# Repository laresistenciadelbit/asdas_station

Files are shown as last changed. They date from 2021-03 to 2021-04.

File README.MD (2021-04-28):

# (A)rduino (S)im (D)ata (A)cquisition (S)ystem

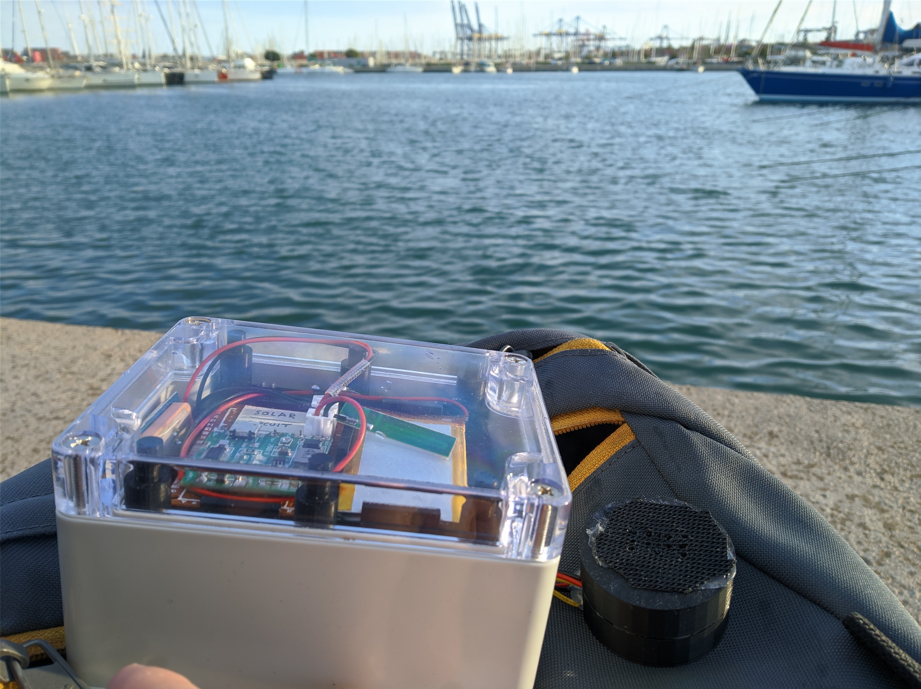
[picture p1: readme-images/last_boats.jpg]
alt asdas_station


[FULL DOCUMENTATION (SPANISH)](https://github.com/laresistenciadelbit/varios/raw/master/ASDAS_PUBLIC_LITE.PDF)

## SPANISH

Arduino Sim Data Acquisition System es un proyecto que cubre toda la parte de
adquisición de datos de sensores desde el circuito físico, a la transmisión de los datos,su almacenaje, y su visualización en tiempo real desde un navegador Web.

Un dispositivo estación hecho con Arduino envía peticiones JSON HTTP POST al servidor.

Este repositorio de Github almacena la parte del dispositivo estación.

La parte del servidor la puedes encontrar en:
[https://github.com/laresistenciadelbit/asdas](https://github.com/laresistenciadelbit/asdas)

#### ESTACIÓN ASDAS

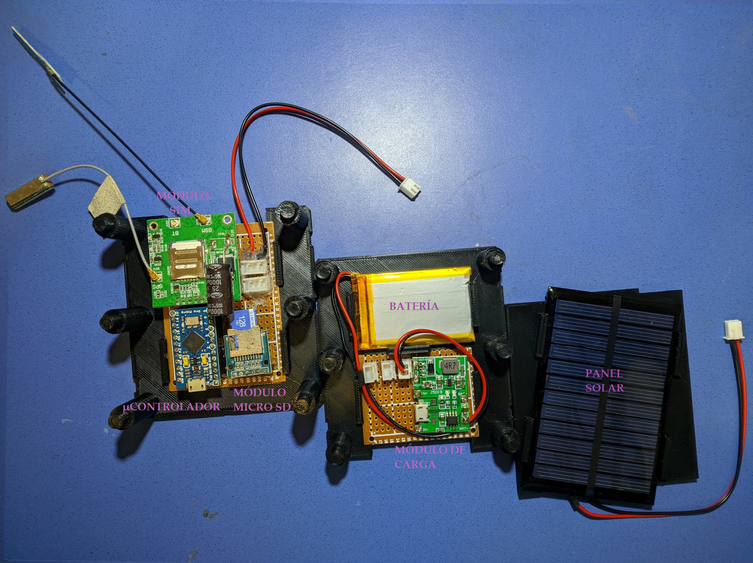
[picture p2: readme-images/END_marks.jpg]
alt asdas_station_circuit


La estación cuenta con un módulo SIM para mandar los datos por la red móvil, un microcontrolador (Arduino Pro Micro versión 3.3V), un lector de tarjetas Micro SD para almacenar los datos que no se hubiesen podido enviar por falta de señal, y un sistema de autonomía con batería, panel solar y un conversor de voltaje que distribuye la energía y carga la batería. También se le añadirán tantos sensores como se desee (hasta el límite de entradas del microcontrolador)

#### CARPETAS DEL PROYECTO

- arduino_sketch

>Aquí encontrarás el sketch para compilarlo en arduino. 

>He tomado la librería oficial de sim808 y la he modificado para hacerla compatible con más módulos y he añadido alguna función.
Es necesario usarla para que funcione el sketch:

[https://github.com/laresistenciadelbit/sim8xx](https://github.com/laresistenciadelbit/sim8xx)

>###### Se instala como el resto de librerías: Se pega su contenido en la carpeta libraries de la carpeta Arduino (o bien la que aparece en mis documentos o bien en la de instalación del programa)

.
- kicad_project

>Aquí encontrarás los esquemas del prototipo de pcb y circuito en formato kicad

.

- blender

>Aquí encontrarás los modelos 3d que forman la estructura para el prototipo

.

alt asdas_station_circuit_timelapse

___
.
## ENGLISH

ASDAS is a project which covers all the data acquisition part of sensors starting from the physical circuit followed by the data transmission, its storage and visualization in real time from a Web Browser.

A station device made with Arduino send HTTP POST JSON messages to the server.

This Github project is the station part.

The server Github can be accessed from:

[https://github.com/laresistenciadelbit/asdas](https://github.com/laresistenciadelbit/asdas)

#### ASDAS STATION

alt asdas_station_circuit

The station counts with a Sim module for sending data to the server throught the mobile network, a microcontroller (Arduino Pro Micro 3.3V), a micro SD reader for storing the data that wouldn't be delivered to the server by signal fail, and an autonomous energy system with battery, solar panel and voltage conversor which distributes energy and charges the battery. Also ther will be added so many sensors as is wished (until the microcontroller I/O ports limit)

#### PROJECT FOLDERS

- arduino_sketch

>Here you can get the sketch for compiling in Arduino

> I've took the official sim808 library and I've modified it for making compatible with more Sim modules and I've also added some function.
The library must be used with this sketch to work:
[https://github.com/laresistenciadelbit/sim8xx](https://github.com/laresistenciadelbit/sim8xx)

>###### The install process for the library is the same like other libraries: Just paste its content in the "libraries" folder from the install directory or "my documents/Arduino" directory.

.
- kicad_project

>Here you can get the pcb and circuit schemas in KiCad format.

.

- blender

>Here you can get the 3d models of the created structure for the prototype

.

alt asdas_station_circuit_timelapse

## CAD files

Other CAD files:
blender_3d_model/tfg_box_battery_v0.d.blend
blender_3d_model/tfg_box_battery_v0.d_HOLED.blend
blender_3d_model/tfg_box_level_v0.8.blend
blender_3d_model/tfg_box_level_v0.8_HOLED.blend
blender_3d_model/tfg_box_solar_v0.B.blend
blender_3d_model/tfg_box_solar_v0.B_HOLED.blend

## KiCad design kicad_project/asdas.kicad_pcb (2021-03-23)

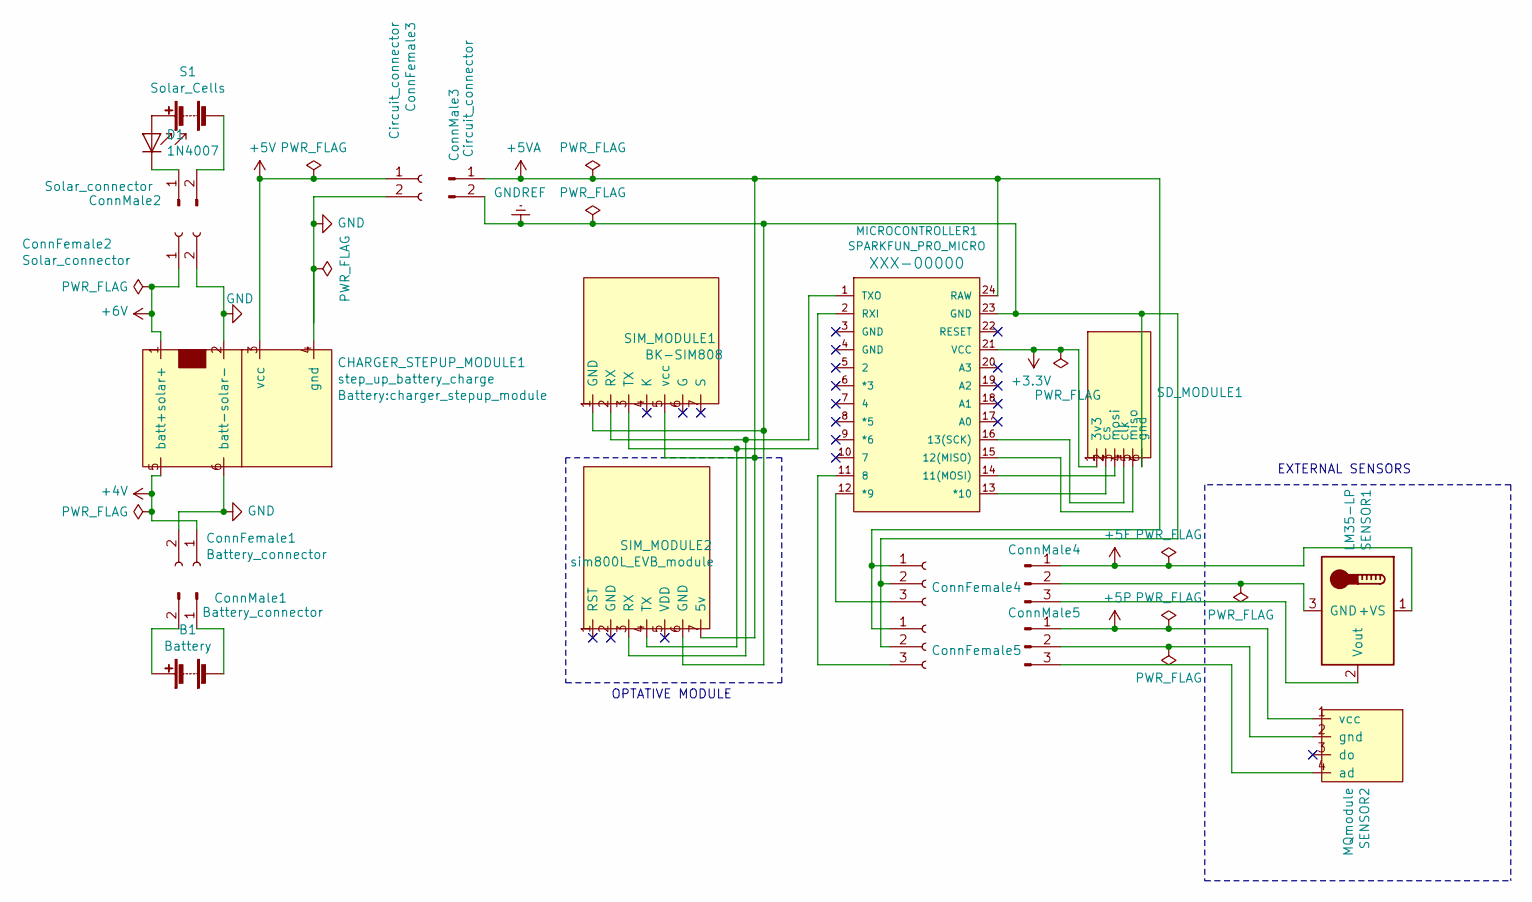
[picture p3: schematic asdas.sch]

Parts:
B1: Battery; battery_523450
CHARGER_STEPUP_MODULE1: step_up_battery_charge; charger_stepup_module
ConnFemale1: Battery_connector; JST_EH_B2B-EH-A_1x02_P2.50mm_Vertical
ConnFemale2: Solar_connector; JST_EH_B2B-EH-A_1x02_P2.50mm_Vertical
ConnFemale3: Circuit_connector; JST_EH_B2B-EH-A_1x02_P2.50mm_Vertical
ConnFemale4: Sensor1_connector; JST_EH_B3B-EH-A_1x03_P2.50mm_Vertical
ConnFemale5: Sensor2_connector; JST_EH_B3B-EH-A_1x03_P2.50mm_Vertical
ConnMale1: Battery_connector; JST_EH_B2B-EH-A_1x02_P2.50mm_Vertical
ConnMale2: Solar_connector; JST_EH_B2B-EH-A_1x02_P2.50mm_Vertical
ConnMale3: Circuit_connector; JST_EH_B2B-EH-A_1x02_P2.50mm_Vertical
ConnMale4: Sensor1_connector; JST_EH_B3B-EH-A_1x03_P2.50mm_Vertical
ConnMale5: Sensor2_connector; JST_EH_B3B-EH-A_1x03_P2.50mm_Vertical
D1: 1N4007; D_DO-41_SOD81_P10.16mm_Horizontal
MICROCONTROLLER1: SPARKFUN_PRO_MICRO
S1: Solar_Cells; solar_cell
SD_MODULE1: sd_reader_2
SENSOR1: LM35-LP; lm35
SENSOR2: MQmodule
SIM_MODULE1: BK-SIM808
SIM_MODULE2: sim800L_EVB_module; sim800L_EVB_module(fixedsize)

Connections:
+3V3: MICROCONTROLLER1.21 (VCC), SD_MODULE1.1 (3v3)
+4V: CHARGER_STEPUP_MODULE1.5 (batt+), ConnFemale1.1
+5F: ConnMale4.1, SENSOR1.1 (+VS)
+5P: ConnMale5.1, SENSOR2.1 (vcc)
+5V: CHARGER_STEPUP_MODULE1.3 (vcc), ConnFemale3.1
+5VA: ConnFemale4.1, ConnFemale5.1, ConnMale3.1, MICROCONTROLLER1.24 (RAW), SIM_MODULE1.5 (vcc), SIM_MODULE2.7 (5v)
+6V: CHARGER_STEPUP_MODULE1.1 (solar+), ConnFemale2.1
GND: CHARGER_STEPUP_MODULE1.2 (solar-), CHARGER_STEPUP_MODULE1.4 (gnd), CHARGER_STEPUP_MODULE1.6 (batt-), ConnFemale1.2, ConnFemale2.2, ConnFemale3.2
GNDREF: ConnFemale4.2, ConnFemale5.2, ConnMale3.2, MICROCONTROLLER1.23 (GND), SD_MODULE1.6 (gnd), SIM_MODULE1.1 (GND), SIM_MODULE2.6 (GND)
unnamed: B1.1 (+), ConnMale1.2
unnamed: B1.2 (-), ConnMale1.1
unnamed: ConnFemale4.3, MICROCONTROLLER1.12 (*9)
unnamed: ConnFemale5.3, MICROCONTROLLER1.11 (8)
unnamed: ConnMale2.1, D1.1 (K)
unnamed: ConnMale2.2, S1.2 (-)
unnamed: ConnMale4.2, SENSOR1.3 (GND)
unnamed: ConnMale4.3, SENSOR1.2 (Vout)
unnamed: ConnMale5.2, SENSOR2.2 (gnd)
unnamed: ConnMale5.3, SENSOR2.4 (ad)
unnamed: D1.2 (A), S1.1 (+)
unnamed: MICROCONTROLLER1.1 (TXO), SIM_MODULE1.2 (RX), SIM_MODULE2.3 (RX)
unnamed: MICROCONTROLLER1.2 (RXI), SIM_MODULE1.3 (TX), SIM_MODULE2.4 (TX)
unnamed: MICROCONTROLLER1.13 (*10), SD_MODULE1.2 (cs)
unnamed: MICROCONTROLLER1.14 (11(MOSI)), SD_MODULE1.3 (mosi)
unnamed: MICROCONTROLLER1.15 (12(MISO)), SD_MODULE1.5 (miso)
unnamed: MICROCONTROLLER1.16 (13(SCK)), SD_MODULE1.4 (clk)

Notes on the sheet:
EXTERNAL SENSORS
OPTATIVE MODULE

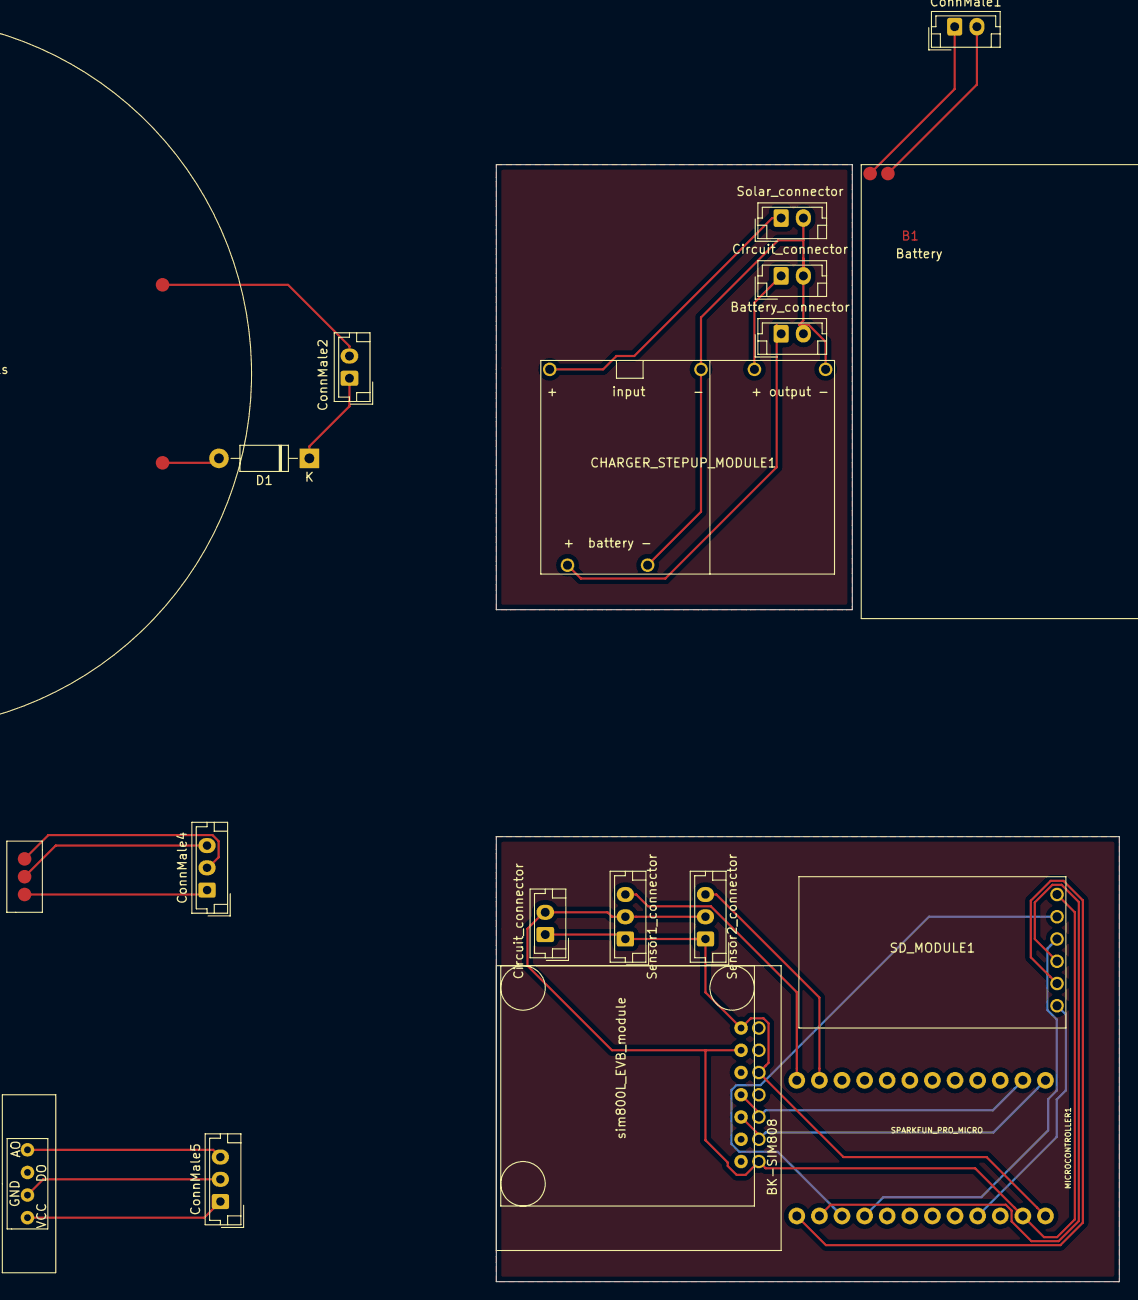
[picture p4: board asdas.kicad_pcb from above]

Board: 2 copper layers, 20 parts (0 on the bottom side), 26 nets.

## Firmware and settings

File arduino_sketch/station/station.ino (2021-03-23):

/*	-Proyecto:	Arduino Sim Data Acquisition System 
	-Autor:		Noel Fernández Peral
	-Requisitos:
		<>Hardware:
			[]Arduino pro micro (Compatible con otras variantes)
			[]Módulo Sim8xx (Cualquier variante de sim800 es compatible)
			[]Módulo de lectura/escritura de tarjeta micro SD
*/
	//definimos el identificador del módulo
#define ID "estación 1"
	//definimos una contraseña para las peticiones
#define PASSWD "1AeIoU!9"
	//Definimos si usaremos gps o no (módulos sim808 y sim868)
#define USE_GPS  1
	//Definimos cuantas estadísticas queremos enviar (sin contar la localización gps)
#define SEND_STATUS 1
	//Definimos si estamos en modo depuración o no
//#define DEBUGGING false // <-- dentro de la clase ModuleManager, ya que el pasarsela como constante asignando a una variable hacía que precompilase el código de debug aunque no se usase
	//Definimos el código pin si la tarjeta lo tiene activo
//#define UNLOCK_PIN "0000"
	//Definimos los credenciales del APN para el uso de GPRS
#define GPRS_APN "internet"
#define GPRS_USER   ""
#define GPRS_PASS   ""
	//pines que usaremos (pines RX y TX dedicados)( RST Y PWKEY para algunos modelos de sim808 y sim7600e )
//#define PIN_RX 		0   USAMOS Serial1 que es puerto de serie por hardware, siempre són los pines 0 y 1 (RXI y TX0) en arduino pro micro
//#define PIN_TX 		1

#define  PIN_RST   7
#define  PIN_PWKEY 6

  //Definimos los pines de los sensores que queremos leer (podemos poner tantos como queramos. *el límite son los pines y la memoria)
#define  SENSOR_NUMBER 2
const uint8_t  sensor_pin[SENSOR_NUMBER]={8,9};
const char  sensor_name[][30]={"temperatura","CO"};
	//Definimos si queremos que se active un pin de salida ante una entrada concreta en el sensor 1
//#define PIN_OUTPUT 13
	//Definimos el valor del sensor 1 para el cual activará el PIN_OUTPUT a HIGH
#define SENSOR1_THRESHOLD 150
  //Definimos un timeout si queremos que el pin de output se desactive tras ese tiempo (ms)
#define OUTPUT_TIMEOUT 6000

	//Definimos la dirección del servidor que recebirá las peticiones
#define  SERVER_ADDRESS "http://post.diab.website"
	//definimos un límite de caracteres para el envío de estado
#define STATUS_CHAR_LIMIT 14

	//Definimos cada cuantos minutos leerá y mandará la información de los sensores
#define WORKING_INTERVAL  5
	//Definimos cuántas veces leerá e intentará enviar la información antes de resetear el microcontrolador por incapacidad de conexión para que reinicie todos los módulos
#define SIM_TIMEOUT_THRESHOLD 5
/*				</FIN DE LA CONFIGURACIÓN DE VARIABLES>				*/

//Incluímos la clase que gestionará la librería del módulo sim
#include "ModuleManager.h"

void setup() //configuración de arranque
{
	// configuramos los pines de salida
	#ifdef PIN_OUTPUT
		pinMode(PIN_OUTPUT, OUTPUT);
	#endif
	pinMode(PIN_PWKEY, OUTPUT);
	pinMode(PIN_RST, OUTPUT);

	for(int8_t i=0; i<SENSOR_NUMBER; i++)
		pinMode(sensor_pin[i], INPUT);
	
///////////// Reset para SIM808 y SIM868 (no usado)
	//#if USE_GPS == true	
//		digitalWrite(PIN_PWKEY, LOW);
//		digitalWrite(PIN_RST, HIGH);
	//#endif
  
	#if DEBUGGING == false	//si no hay debugging por puerto de serie usamos el led de RX como indicador
		pinMode(17, OUTPUT);
	#endif
}

/*  build_status_array():
		Rellena los vectores de datos de estado
			i->contador
			a->vector destino
			aa->cadena
			b->vector destino
			bb->cadena
*/
void build_status_array(uint8_t *i, char a[][STATUS_CHAR_LIMIT], char *aa, char b[][STATUS_CHAR_LIMIT], char *bb)
{
	strlcpy(a[*i],aa,sizeof(a[*i]));
	strlcpy(b[*i],bb,sizeof(b[*i]));
	*i=*i+1;
}

void loop()
{
	bool http_post_correct;
	uint8_t sensor_value[SENSOR_NUMBER];
	char sensor_value_str_buffer[4];  //leemos el sensor con resolución de 10 bits, como máximo será un valor de 1024 (4 caracteres)
	char sim_unlock_pin[4]={NULL,NULL,NULL,NULL};
	#ifdef UNLOCK_PIN
		strlcpy(sim_unlock_pin,UNLOCK_PIN,sizeof(4));
	#endif

	char status_name[SEND_STATUS+2][STATUS_CHAR_LIMIT]; //+2 del gps (latitud,longitud)
	char status_data[SEND_STATUS+2][STATUS_CHAR_LIMIT];
	uint8_t total_status;
	char satellites[3]; 	//opcional
	char battery[3]; 		//opcional
	
	uint8_t sim_timeout_counter=0;
	bool reset_modules=false;

	unsigned long working_interval_mili=WORKING_INTERVAL*60L*1000L;
	unsigned long previousMillis = millis();
	unsigned long currentMillis = previousMillis; //las inicializamos igual puesto que arduino puede reiniciar el loop sin reinicializar los contadores

	ModuleManager ASDAS(PASSWD,ID,SERVER_ADDRESS,USE_GPS,PIN_PWKEY,PIN_RST,sim_unlock_pin,GPRS_APN,GPRS_USER,GPRS_PASS);
	//Sim ASDAS(SERVER_ADDRESS,USE_GPS,DEBUGGING, UNLOCK_PIN); // <- si tenemos código pin configurado en la tarjeta, usaremos esta inicialización de clase
	#if DEBUGGING==false
		digitalWrite(17, LOW);delay(200);digitalWrite(17, HIGH);delay(200);digitalWrite(17, LOW);delay(200);digitalWrite(17, HIGH);delay(200);digitalWrite(17, LOW);delay(200);digitalWrite(17, HIGH);delay(200);digitalWrite(17, LOW);delay(200);digitalWrite(17, HIGH);delay(200);
	#endif

	if(USE_GPS)
	{	// dos minutos de espera al arranque para que coja señal gps
		digitalWrite(17, LOW);delay(30000);digitalWrite(17, HIGH);delay(30000);
		digitalWrite(17, LOW);delay(30000);digitalWrite(17, HIGH);delay(30000);
		#if DEBUGGING == true
			Serial.println(F("Waiting 2 minutes for the gps signal..."));
		#endif
	}
 
	/*módulo arrancado, conectado a red y a gps*/
	if(ASDAS.is_full_connected())
	{
		#if DEBUGGING == true
			  Serial.println(F("[+]Connected to 2g"));
		#endif
		ASDAS.prevention_delay(); //damos 3 segundos de estabilización
	}
	
	while(!reset_modules)
	{
		#if DEBUGGING == true
			  Serial.println(F("Reading sensors..."));
		#endif
		//Toma los valores de los sensores
		for(uint8_t i=0; i<SENSOR_NUMBER; i++)
		{
			sensor_value[i]=ASDAS.get_sensor_val(sensor_pin[i]);

			#if DEBUGGING == true
			Serial.println(F("")); Serial.print(F("[+]Sensor: ")); Serial.print(sensor_name[i]); Serial.print(F(" value: ")); Serial.print(sensor_value[i]); Serial.println(F(""));
			#endif
			
			#ifdef PIN_OUTPUT
				if(i==0 && sensor_value[i]>SENSOR1_THRESHOLD)
				{
					digitalWrite(PIN_OUTPUT, HIGH); //superó el valor límite el sensor1: activamos la salida por el pin de salida
         
					#ifdef OUTPUT_TIMEOUT //la desactivamos tras un tiempo si hemos definido el timeout
						delay(OUTPUT_TIMEOUT);
						digitalWrite(PIN_OUTPUT, LOW);
					#endif
          
				} else
					digitalWrite(PIN_OUTPUT, LOW);					
			#endif
		}
			
	//Toma el tiempo actual del reloj del módulo sim
		ASDAS.get_time();
		
	//Toma la posición gps
		#if DEBUGGING == true
			if(USE_GPS)
				Serial.println(F("Obtaining GPS location..."));
		#endif

		if(USE_GPS)
			ASDAS.get_gps();

		#if DEBUGGING == true
			Serial.println(F("Looking for data in the SD buffer..."));
		#endif
			
		if( ASDAS.is_full_connected() )
		{
			while( ASDAS.data_waiting_in_sd() )	//mientras haya líneas en el fichero de almacenamiento
			{
				if(!ASDAS.send_last_sd_line())	//las envía, si falla al enviar se sale
					break;
				ASDAS.prevention_delay();
			}
		//Envía los datos obtenidos de los sensores
			#if DEBUGGING == true
				Serial.println(F("Sending sensor data..."));
			#endif
			http_post_correct=true;	//la tomamos por buena desde el principio para que quede como falsa en cualquiera de las peticiones que llegasen a dar error en toda la iteración.
			for(uint8_t sensor_number=0; sensor_number<SENSOR_NUMBER; sensor_number++)
			{
			//convertimos en cadena de caracteres el valor del sensor				<a--- meterlo para devolver en una función en la clase Sensores
				itoa(sensor_value[sensor_number],sensor_value_str_buffer,10);

			//envía la petición http_post
				if( !ASDAS.send_data_to_server(sensor_name[sensor_number], sensor_value_str_buffer ) )
				{
					ASDAS.save_data_in_sd(sensor_name[sensor_number], sensor_value_str_buffer);	//si la petición post devolvió error: escribe los datos del sensor a la tarjeta sd
					http_post_correct = false;
				}
				ASDAS.prevention_delay();
			}

		//Envía los estados y ubicación
			#if DEBUGGING == true
				Serial.println(F("Sending status data..."));
			#endif
			if( (SEND_STATUS || USE_GPS) )
			{
				total_status=0;
		  
				if (SEND_STATUS) //aquí rellenamos el array de status_data si queremos mandar más datos adicionales (porcentaje de batería, satélites detectados, errores...)
				{
					  //OPCIONAL (estado de la batería)
					itoa( ASDAS.battery_left(), battery, 10 );
					build_status_array( &total_status, status_name, "battery" , status_data, battery);

					/* 
					  //OPCIONAL (satélites encontrados)
					itoa( ASDAS.get_satellites_found(), satellites, 10 );
					build_status_array( &total_status,  status_name, "satellites", status_data, satellites  );
				
					  //OPCIONAL (error encontrado al activar un flag)
					if(flag_error_example1 || flag_error_example2 || flag_error_example3 )
					{
						build_status_array( &total_status, status_name, "error", status_data, error_content );
					}
					*/
				}
				if( USE_GPS && ASDAS.got_gps_position() )
				{
					build_status_array( &total_status, status_name, "lat", status_data, "" );
					build_status_array( &total_status, status_name, "lon", status_data, "" );
				}
				
				for( uint8_t status_count=0; status_count<total_status; status_count++ )
				{
					if(http_post_correct)
					{
						http_post_correct = ASDAS.send_aditional_data_to_server(status_name[status_count],status_data[status_count]);
						ASDAS.prevention_delay();
						if( !http_post_correct )
							ASDAS.save_aditional_data_in_sd(status_name[status_count],status_data[status_count]);
					}
					else
						ASDAS.save_aditional_data_in_sd(status_name[status_count],status_data[status_count]);
           
					ASDAS.prevention_delay();
				}
			}
		}

		#if DEBUGGING == true
			Serial.print(F("\n * * * END!!! - Waiting ")); Serial.print(WORKING_INTERVAL); Serial.print(F("minutes...\n"));
		#endif
		
		// !!! APAGAMOS (gps y/o gprs) ??? ->>>>>>
		//		ASDAS.gprsDisconnect();
		//    	ASDAS.gpsDisconnect();
		//		if(DEBUGGING)Serial.println(F("Radios disconnected"));
		// !!! PONEMOS EN MODO AHORRO DE ENERGÍA ??? 

		while (currentMillis - previousMillis < working_interval_mili)  //se mantiene en el bucle hasta que pase el tiempo de espera
		{
		  #if DEBUGGING == true
			Serial.println(F("waiting..."));
		  #endif
		  delay(1000);
		  currentMillis = millis();
		}

		previousMillis = currentMillis; //reseteamos el contador
			
		if( !ASDAS.is_full_connected() || !http_post_correct ) //si no se consiguió conectar o falló al enviar alguna petición web
		{
			if(sim_timeout_counter == SIM_TIMEOUT_THRESHOLD)
			{
				sim_timeout_counter=0;
				reset_modules=true;
			}
			else
				sim_timeout_counter++;
		}
		if(http_post_correct)
			sim_timeout_counter=0;
	}
}

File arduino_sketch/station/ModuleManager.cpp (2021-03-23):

#include <SPI.h>
#include "SdFat.h"
#include <SIM8xx.h>

#include "ModuleManager.h"

ModuleManager::ModuleManager(const char* passwd, const char *id, const char *server, const bool gps, const int8_t pwkey, const int8_t rst ,char *pin, char *apn, char *apn_user, char *apn_pass)
{
	strcpy(this->station_id,id);
	strcpy(this->server_address,server);
	strcat(this->server_address,"/?pw=");
	strcat(this->server_address,passwd);

	strcpy(this->gprs_apn,apn);
	if(apn_user[0]!=0)
	{
		strcpy(this->gprs_user,apn_user);
		strcpy(this->gprs_pass,apn_pass);
	} else {
    this->gprs_user[0]=0;
    this->gprs_pass[0]=0;
	}
  
	if(pin[0]!=0)
	{
		strlcpy(this->sim_pin,pin,4);
	}
	else
		this->sim_pin[0]=0;

//Inicializamos comunicación con el pc solo para debugging
  #if DEBUGGING == true
    Serial.begin(115200); //iniciamos el puerto de comunicación del microcontrolador (recomendado >9600 y <115200)
    while (!Serial) {;}
    prevention_delay();
    Serial.println(F("Loading ModuleManager..."));
    Serial.println(this->server_address);
  #endif

// Inicializamos módulos

	// Inicializamos módulo micro SD
	if (!SD.begin(10))  //Pin ss está definido como pin 10
	{
		#if DEBUGGING == true
			Serial.println(F("[-]SD initialization failed!"));
		#endif
	}
	else
	{
		#if DEBUGGING == true
			Serial.println(F("[+]SD initialization done."));
		#endif
	}
  
//Inicializamos comunicación en serie desde microcontrolador a módulo sim
	Serial1.begin(9600);	//iniciamos la vía de comunicación con el módulo sim
	
	#if DEBUGGING == true
		Serial.println(F("Starting Sim8xx..."));
	#endif
      
	prevention_delay();
	this->sim_module = new SIM8xx(rst,pwkey);//SIM_RST, SIM_PWR);   // <- arduino no permite instanciar clases, por lo que creamos la clase SIM8xx y la inicializamos directamente desde la definicion de esta clase (en ModuleManager.h)
	this->sim_module->begin(Serial1);
	this->sim_module->powerOnOff(true);
	this->sim_module->init(); 
	
	if (gps)
	{
		this->use_gps=true;
		sim_module->powerOnOffGps(true);
	}
	else
		this->use_gps=false;
    
	if( connect_network(0) )
	{
		this->connection_successful=connect_gprs(0);
	}
	else
		this->connection_successful=false;
}

bool ModuleManager::is_full_connected(void){return this->connection_successful;}

bool ModuleManager::connect_network(uint8_t intento=0)
{
	SIM8xxNetworkRegistrationState network_status;
	bool return_status;
	
	this->unlock_sim();

	#if DEBUGGING == true
		Serial.println(S_F("[*]Waiting for network..."));
	#endif
	
	network_status = sim_module->getNetworkRegistrationStatus();
	if( !(static_cast<int8_t>(network_status) & (static_cast<int8_t>(SIM8xxNetworkRegistrationState::Registered) | static_cast<int8_t>(SIM8xxNetworkRegistrationState::Roaming)) != 0) )
	{
		#if DEBUGGING == true
			Serial.println(S_F(" [-]Fail"));
		#endif
    
		if(intento>4)
			return_status=false;//resetSoftware();
		else
		{
			delay(12500);
			return_status=connect_network(intento+1);	//recursivo
		}
	}
	else
	{
		#if DEBUGGING == true
			Serial.println(S_F("[+]Network connected"));
		#endif
		return_status=true;
	}
	return return_status;
}

bool ModuleManager::connect_gprs(uint8_t intento=0)
{
	bool return_status;
	
	this->unlock_sim(); //solo desbloquea en caso de que no se haya desbloqueado (que ya debería estarlo)
	
	#if DEBUGGING == true
		Serial.println(S_F("[*]Connecting to 2g network"));
	#endif

    sim_module->disableGprs(); //forzamos la desconexión de la red de datos por si lo estuviera (esto solo pasaría si por un motivo se resetea/reinicia/apaga arduino pero no el módulo sim) (esto se podría mejorar haciendo un chequeo de "AT+SAPBR=2,1" y que nos devuelva la ip que nos ha asignado, en caso negativo devuelve 0.0.0.0)
    prevention_delay();

    if( !sim_module->enableGprs(gprs_apn,gprs_user,gprs_pass)) //si no consigue conectar
    {
		#if DEBUGGING == true
			Serial.println(S_F(" [-]Fail"));
		#endif
		delay(8500);

      //reintentamos recursivamente antes de reiniciar:
  		if(intento>3)
  			return_status=false;//resetSoftware();
  		else
  		{
  			delay(8500);
  			connect_gprs(intento+1);	//recursivo
  		}
    } 
  	else
  	{
  		return_status=true;
		prevention_delay();
  		#if DEBUGGING == true
			Serial.println(S_F("[+]GPRS connected"));
		#endif
  	}
	  return return_status;
}

void ModuleManager::unlock_sim(void)
{
  
    if ( this->sim_pin[0] != 0 )	//si se definió pin de la tarjeta sim, se desbloquea
    {
      sim_module->getSimState(parameters_buffer, PARAMETERS_SIZE);
      
      if( strcmp(parameters_buffer,"SIM PIN")==0 )
      {
		#if DEBUGGING == true
			Serial.println(S_F("[*]unlocking sim pin"));
		#endif
		sim_module->simUnlock(this->sim_pin);
		prevention_delay();
		prevention_delay();
      }
	}	
}

int8_t ModuleManager::get_sensor_val(uint8_t sensor_pin){	return analogRead(sensor_pin);	}

void ModuleManager::get_time(void/*char *clock_output*/) //tomamos la hora del reloj del módulo sim (cada vez que se conecta a la red se sincroniza automáticamente)
{
	//formato: "20/09/20,04:23:58+08" el 08 es el timezone en cuartos de hora, así que hay que dividirlo entre 4 para que sea el equivalente a 1 hora, así obtendríamos nuestro +2 oficial (pero hay que recordar que la hora ya está con el +2 incluído, así que tal vez debiéramos restarle el +2 a la hora para sumarselo en el servidor al huso horario configurado en él)
	sim_module->getInternalClock(this->current_time);	//<- anteriormente lo devolvíamos al main, ahora lo gestionamos desde la clase
  #if DEBUGGING == true
    Serial.println(F("[*]Getting clock...:")); Serial.println(this->current_time);
  #endif
  prevention_delay();
}

uint8_t ModuleManager::battery_left(void)	
{   // <!!!> se la daremos al HTTP POST como estado si así lo hemos indicado / o lo usaremos para ponerlo en modo bajo consumo
	return sim_module->getBattStat();
}

uint8_t ModuleManager::get_satellites_found(void)
{
	return this->sat;
}

bool ModuleManager::got_gps_position(void)
{  return this->gps_position_found;  }
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

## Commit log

2021-01-30 -fixed strcpy & strcat -fixed apn user & pass NULL pointer detection -realized Serial1 is on TX0 & RXI -raised timeout of AT commands from Sim8xx library -clock output response (fixed in Sim8xx libra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
    [ModuleManager.cpp, station.ino]
2021-02-03 -fixed status counter not raising due to pointer -modified and added the use of a function in library sim8xx to read gprs status -status http petitions were malformed
    [ModuleManager.cpp, station.ino]
2021-02-04 -improved delay managemente (now using millis()) -fixed sd reading lines
    [ModuleManager.cpp, station.ino]
2021-02-17 -fixed network registration status if not working properly -sketch exceeded available space when compiling with: USE_GPS 1 >shared buffer between gps and http parameters >convert some int into uint8_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
    [ModuleManager.cpp, station.ino]
2021-03-23 - added readme, circuit sketch, and blender model
    [asdas.kicad_pcb, asdas.sch, tfg_box_battery_v0.d.blend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]
